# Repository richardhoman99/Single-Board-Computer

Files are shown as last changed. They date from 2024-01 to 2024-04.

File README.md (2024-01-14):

# Single Board Computer

CPGR4253 Microcomputer Design is not as much a technical course at LeTourneau University as it is a design project. The goal of the course is to design a functioning Single Board Computer with the following requirements:
- A microprocessor
- At least 64Kib RAM
- ROM memory to store monitor program
- Serial connection to external terminal

This repository is the container of all digital files supporting this project.

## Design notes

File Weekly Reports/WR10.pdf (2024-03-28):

Richard Homan

Microcomputer Design

Dr. Joonwan Kim

March 27, 2024

Design Report #10

I. Time: 15 Hours

II. Accomplishments

A. Programmed working CPLD program
B. Successfully programed ROM

III. Planned Work

A. Figure out halting issue
B. Run ROM/RAM test program
C. Run DUART base code and pass characters from board to laptop

IV. Project Completion

A. Hardware: 98%; Assembly complete, actively looking out for mistakes during software testing
B. Software: 85%; Monitor program 95% done, serial recognized and able to accept characters
V. Help from Lab Tech
A. n/a

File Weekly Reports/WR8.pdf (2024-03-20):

Richard Homan

Microcomputer Design

Dr. Joonwan Kim

March 6, 2024

Design Report #8

I. Time: 5 Hours

II. Accomplishments

A. Began soldering board

III. Planned Work

A. Complete board assembly
B. Program CPLD logic
C. Test burn EEPROM

IV. Project Completion

A. Hardware: 95%; Assembly almost complete
B. Software: 75%; Monitor program 95% done
V. Help from Lab Tech
A. n/a

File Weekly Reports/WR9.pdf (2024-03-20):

Richard Homan

Microcomputer Design

Dr. Joonwan Kim

March 20, 2024

Design Report #9

I. Time: 16 Hours

II. Accomplishments

A. Completed soldering board
B. Found power and serial issues with board, rectified by cutting traces
C. Board serial successfully recognized by Mac and Windows machines
D. Successfully programmed CPLD with test program

III. Planned Work

A. Write CPLD logic
B. Write serial test program
C. Burn serial test program onto ROM and test functionality
D. Combine serial and written monitor program, burn to ROM, and test

IV. Project Completion

A. Hardware: 98%; Assembly complete, actively looking out for mistakes during software testing
B. Software: 80%; Monitor program 95% done, serial recognized and able to accept characters
V. Help from Lab Tech
A. n/a

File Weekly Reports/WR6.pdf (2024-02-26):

Richard Homan

Microcomputer Design

Dr. Joonwan Kim

February 21, 2024

Design Report #6

I. Time: 22 Hours

II. Accomplishments

A. Finished monitor program on simulator

III. Planned Work

A. Receive and assemble board
B. Program CPLD logic
C. Test burn EEPROM

IV. Project Completion

A. Hardware: 90%; PCB ordered, parts recieved
B. Software: 75%; Monitor program 95% done
V. Help from Lab Tech
A. 2/15/23 - Basic checkup

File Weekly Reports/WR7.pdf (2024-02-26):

Richard Homan

Microcomputer Design

Dr. Joonwan Kim

February 28, 2024

Design Report #7

I. Time: 0 Hours

II. Accomplishments

A. n/a (Board ordered and shipped but still not received)

III. Planned Work

A. Receive and assemble board
B. Program CPLD logic
C. Test burn EEPROM

IV. Project Completion

A. Hardware: 90%; PCB ordered, parts received
B. Software: 75%; Monitor program 95% done
V. Help from Lab Tech
A. 2/22/23 - Basic checkup

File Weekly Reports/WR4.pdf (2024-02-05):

Richard Homan

Microcomputer Design

Dr. Joonwan Kim

February 7, 2024

Design Report #4

I. Time: 15 Hours

II. Accomplishments

A. PCB 99% complete

III. Planned Work

A. Finish PCB design and find a manufacturer
B. Set up C compiler environment
C. Begin software design

IV. Project Completion

A. Hardware: 75%; PCB almost ready to be manufactured
B. Software: 0%
V. Help from Lab Tech
A. 2/1/2024 - Discussed the future of MCD class

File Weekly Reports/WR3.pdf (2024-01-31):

Richard Homan

Microcomputer Design

Dr. Joonwan Kim

January 31, 2024

Design Report #3

I. Time: 26 Hours

II. Accomplishments

A. Parts are ordered
B. Final schematic complete
C. 85% done on PCB
D. Compared parts with peers
E. Had schematic reviewed

III. Planned Work

A. Finish PCB design and find a manufacturer

IV. Project Completion

A. Hardware: 60%; working on PCB
B. Software: 0%
V. Help from Lab Tech
A. 1/26/2024 - Reviewed final schematic and made recommended changes

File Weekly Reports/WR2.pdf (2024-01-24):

Microcomputer Design

Dr. Joonwan Kim

January 24, 2024

Design Report #2

I. Time: 13 Hours

II. Accomplishments

A. Researched more hardware options
B. Researched PCB manufacturing places to get specs on fabrication
C. Made schematic revision 0.2

III. Planned Work

A. Compare parts with peers
B. Create footprints for parts
C. Review schematic with Lab Assistant

IV. Project Completion

A. Hardware: 35%; Rev. 0.2 complete
B. Software: 0%
V. Help from Lab Tech
A. 1/18/2024 - Reviewed the CTS and RTS pin functions, looked over clock and reset circuit.

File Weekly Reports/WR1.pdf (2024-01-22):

Microcomputer Design

Dr. Joonwan Kim

January 18, 2024

Design Report #1

I. Time: 37 Hours

II. Accomplishments

A. Researched different hardware options; 95% confident in selection
B. Tested a few power switching circuit designs
C. Tested RAM circuit
D. Finished Rev. 0 of schematic

III. Planned Work

A. Review schematic and my custom symbols for correctness
B. Compare pinouts with peers
C. Compare parts lists with peers
D. Have schematic reviewed by lab tech

IV. Project Completion

A. Hardware: 30%; Rev. 0 complete
B. Software: 0%
V. Help from Lab Tech
A. 1/18/2024 - Reviewed the CTS and RTS pin functions, looked over clock and reset circuit.

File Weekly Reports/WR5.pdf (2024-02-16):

Richard Homan

Microcomputer Design

Dr. Joonwan Kim

February 14, 2024

Design Report #5

I. Time: 23 Hours

II. Accomplishments

A. Got C compiler and linker working for m68k
B. Finish memory and register modification and dumping for monitor program

III. Planned Work

A. Finish screcord loading and storing
B. Write executable to ROM

IV. Project Completion

A. Hardware: 90%; PCB ready to be manufactured
B. Software: 40%; Monitor program 45% done
V. Help from Lab Tech
A. 2/09/23 - Discuss which files get submitted to manufacturer

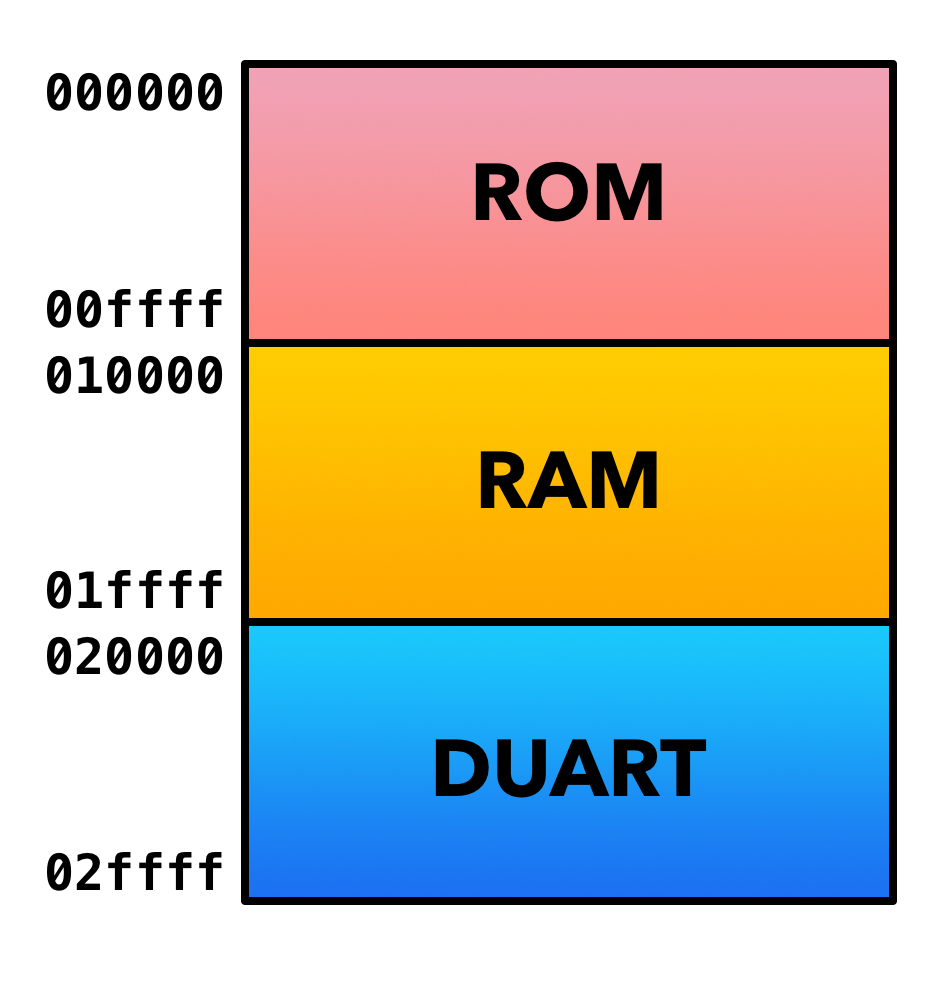
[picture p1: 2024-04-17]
Memory Map.png

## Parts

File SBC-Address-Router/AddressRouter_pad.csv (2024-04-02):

Release 8.1i - Fit P.20131013
Copyright(c) 1995-2003 Xilinx Inc. All rights reserved
4- 1-2024 2:27AM
NOTE: This file is designed to be imported into a spreadsheet program
such as Microsoft Excel for viewing | printing and sorting. The comma ' | '
character is used as the data field separator.
This file is also designed to support parsing.
Input file: AddressRouter.ngd
output file: AddressRouter_pad.csv
Part type: xc9572xl
Speed grade: -10
Package: pc44
Pinout by Pin Number:
----- | ----- | ----- | ----- | ----- | ----- | ----- | ----- | ----- | -----
Pin Number | Signal Name | Pin Usage | Pin Name | Direction | IO Standard | IO Bank Number | {blank} | Slew Rate | Termination | {blank} | Voltage | Constraint
P1 | o_cs_duart | O | I/O | OUTPUT
P2 | i_duart_dtack | I | I/O | INPUT
P3 | o_duart_rw | O | I/O | OUTPUT
P4 | TIE |  | I/O
P5 | i_clk | GCK | I/O/GCK1
P6 | o_oe | O | I/O/GCK2 | OUTPUT
P7 | o_we | O | I/O/GCK3 | OUTPUT
P8 | o_cs_ramh | O | I/O | OUTPUT
P9 | o_cs_raml | O | I/O | OUTPUT
P10 | GND |  | GND
P11 | TIE |  | I/O
P12 | o_ipl<0> | O | I/O | OUTPUT
P13 | TIE |  | I/O
P14 | o_ipl<1> | O | I/O | OUTPUT
P15 | TDI |  | TDI
P16 | TMS |  | TMS
P17 | TCK |  | TCK
P18 | o_berr | O | I/O | OUTPUT
P19 | TIE |  | I/O
P20 | o_ipl<2> | O | I/O | OUTPUT
P21 | VCC |  | VCCINT
P22 | o_hlt | O | I/O | OUTPUT
P23 | GND |  | GND
P24 | o_dtack | O | I/O | OUTPUT
P25 | i_rw | I | I/O | INPUT
P26 | i_lds | I | I/O | INPUT
P27 | i_uds | I | I/O | INPUT
P28 | i_as | I | I/O | INPUT
P29 | TIE |  | I/O
P30 | TDO |  | TDO
P31 | GND |  | GND
P32 | VCC |  | VCCIO
P33 | TIE |  | I/O
P34 | TIE |  | I/O
P35 | TIE |  | I/O
P36 | TIE |  | I/O
P37 | i_addr<1> | I | I/O | INPUT
P38 | TIE |  | I/O
P39 | i_addr<0> | I | I/O/GSR | INPUT
P40 | o_cs_roml | O | I/O/GTS2 | OUTPUT
P41 | VCC |  | VCCINT
P42 | o_duart_iack | O | I/O/GTS1 | OUTPUT
P43 | o_cs_romh | O | I/O | OUTPUT
P44 | i_rst | I | I/O | INPUT
To preserve the pinout above for future design iterations in
Project Navigator simply execute the (Lock Pins) process
located under the (Implement Design) process in a toolbox named
(Optional Implementation Tools) or invoke PIN2UCF from the
command line. The location constraints will be written into your
specified UCF file

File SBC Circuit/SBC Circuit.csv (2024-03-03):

Source: | /Users/richardhoman/Education/2024-Spring/CPGR4253/SBC Circuit/SBC Circuit.kicad_sch
Date: | Friday, March 01, 2024 at 03:02:21 PM
Tool: | Eeschema 7.0.10
Generator: | /Applications/KiCad/KiCad.app/Contents/SharedSupport/plugins/bom_csv_grouped_by_value.py
Component Count: | 89
Collated Components:
Item | Qty | Reference(s) | Value | LibPart | Footprint | Datasheet | DNP | ROLE | Role | Role2 | Sim.Device | Sim.Pins
1 | 3 | C1, C2, C3 | 4.7u | Device:C_Polarized_US | Capacitor_THT:CP_Radial_D4.0mm_P2.00mm | ~
2 | 1 | C4 | 10n | Device:C | Capacitor_THT:CP_Disc_L5.50mm_W4.00mm_P2.50mm_NonPolarized | ~
3 | 9 | C5, C6, C8, C10, C12, C14, C16, C18, C30 | 0.1u | Device:C | Capacitor_THT:CP_Disc_L5.50mm_W4.00mm_P2.50mm_NonPolarized | ~
4 | 13 | C7, C9, C11, C13, C15, C17, C19, C21, C23, C25, C27, C29, C31 | 1u | Device:C | Capacitor_THT:CP_Disc_L5.50mm_W4.00mm_P2.50mm_NonPolarized | ~
5 | 6 | C20, C22, C24, C26, C28, C32 | .1u | Device:C | Capacitor_THT:CP_Disc_L5.50mm_W4.00mm_P2.50mm_NonPolarized | ~
6 | 2 | C33, C34 | 47p | Device:C | Capacitor_THT:CP_Disc_L5.50mm_W4.00mm_P2.50mm_NonPolarized | ~
7 | 2 | D1, D2 | 1N4001 | Diode:1N4933-T | Diode_THT:D_DO-41_SOD81_P5.08mm_Vertical_KathodeUp | http://www.vishay.com/docs/88503/1n4001.pdf |  |  | BACKFLOW RECTIFIER |  | D | 1=K 2=A
8 | 4 | D3, D4, D5, D6 | LED | Device:LED | LED_THT:LED_D5.0mm | ~
9 | 2 | F1, F2 | 250mA Fuse | Device:Fuse | Fuse:Fuseholder_Clip-5x20mm_Bel_FC-203-22_Lateral_P17.80x5.00mm_D1.17mm_Horizontal | ~
10 | 1 | FB1 | FerriteBead | Device:FerriteBead | Capacitor_THT:C_Axial_L3.8mm_D2.6mm_P10.00mm_Horizontal | ~
11 | 1 | J1 | USB_B | Connector:USB_B | Connector_USB:USB_B_OST_USB-B1HSxx_Horizontal | ~
12 | 2 | J2, J8 | Conn_01x02_Pin | Connector:Conn_01x02_Pin | Connector_PinHeader_2.54mm:PinHeader_1x02_P2.54mm_Vertical | ~ |  |  | POWER IN
13 | 3 | J3, J4, J7 | Conn_01x06_Pin | Connector:Conn_01x06_Pin | Connector_PinHeader_2.54mm:PinHeader_1x06_P2.54mm_Vertical | ~ |  | PERIPHERAL IN | USB SERIAL CONVERTER HEADER
14 | 1 | J5 | Conn_01x03_Pin | Connector:Conn_01x03_Pin | Connector_PinHeader_2.54mm:PinHeader_1x03_P2.54mm_Vertical | ~ |  |  | PERIPHERAL POWER
15 | 1 | J6 | Conn_01x08_Pin | Connector:Conn_01x08_Pin | Connector_PinHeader_2.54mm:PinHeader_1x08_P2.54mm_Vertical | ~ |  |  | PERIPHERAL OUT
16 | 1 | J9 | Conn_02x04_Odd_Even | Connector_Generic:Conn_02x04_Odd_Even | Connector_PinHeader_2.54mm:PinHeader_2x04_P2.54mm_Vertical | ~ |  |  | CHANNEL SELECT
17 | 2 | Q1, Q2 | AOI21357 | Transistor_FET:AOI21357 | Package_TO_SOT_THT:TO-220-3_Vertical | http://www.irf.com/product-info/datasheets/data/irf9540n.pdf |  |  | 5V SOURCE SWITCHER
18 | 1 | R1 | 1M | Device:R | Resistor_THT:R_Axial_DIN0204_L3.6mm_D1.6mm_P2.54mm_Vertical | ~ |  |  | LOW WASTE PULLDOWN
19 | 2 | R2, R3 | 27 | Device:R | Resistor_THT:R_Axial_DIN0204_L3.6mm_D1.6mm_P2.54mm_Vertical | ~
20 | 5 | R4, R5, R6, R8, R13 | 10k | Device:R | Resistor_THT:R_Axial_DIN0204_L3.6mm_D1.6mm_P2.54mm_Vertical | ~
21 | 1 | R7 | 5.6k | Device:R | Resistor_THT:R_Axial_DIN0204_L3.6mm_D1.6mm_P2.54mm_Vertical | ~
22 | 1 | R9 | 470 | Device:R | Resistor_THT:R_Axial_DIN0204_L3.6mm_D1.6mm_P2.54mm_Vertical | ~
23 | 3 | R10, R11, R12 | 220 | Device:R | Resistor_THT:R_Axial_DIN0204_L3.6mm_D1.6mm_P2.54mm_Vertical | ~
24 | 1 | SW1 | RESET | Switch:SW_Push | Button_Switch_THT:SW_PUSH_6mm | ~
25 | 1 | TP1 | GND POINT | Connector:TestPoint | TestPoint:TestPoint_Keystone_5000-5004_Miniature | ~
26 | 1 | TP2 | 5V TEST | Connector:TestPoint | TestPoint:TestPoint_Keystone_5000-5004_Miniature | ~
27 | 1 | TP3 | 3.3V TEST | Connector:TestPoint | TestPoint:TestPoint_Keystone_5000-5004_Miniature | ~
28 | 1 | TP4 | ~{RST} | Connector:TestPoint | TestPoint:TestPoint_Keystone_5000-5004_Miniature | ~
29 | 1 | TP5 | VBUS SENSE | Connector:TestPoint | TestPoint:TestPoint_Keystone_5000-5004_Miniature | ~
30 | 1 | TP6 | ~{AS} | Connector:TestPoint | TestPoint:TestPoint_Keystone_5000-5004_Miniature | ~
31 | 1 | TP7 | ~{DTACK} | Connector:TestPoint | TestPoint:TestPoint_Keystone_5000-5004_Miniature | ~
32 | 1 | TP8 | ~{BERR} | Connector:TestPoint | TestPoint:TestPoint_Keystone_5000-5004_Miniature | ~
33 | 1 | U1 | MC68000FN | CPU_NXP_68000:MC68000FN | Package_LCC:PLCC-68_THT-Socket | https://www.nxp.com/docs/en/reference-manual/MC68000UM.pdf |  |  | MICROPROCESSOR
34 | 1 | U2 | XC9572XL | CPLD_Xilinx:XC9572XL-PC44 | Package_LCC:PLCC-44_THT-Socket |  |  |  |  | ADDRESS ROUTER
35 | 1 | U3 | 68681 | Interface:68681 | Package_DIP:DIP-40_W15.24mm_Socket |  |  |  | DUART
36 | 2 | U4, U5 | MCM6206CP | Memory_RAM:MCM6206CP | Package_DIP:DIP-28_W7.62mm_Socket | https://www.futurlec.com/Datasheet/Memory/62256.pdf |  |  | LOW
37 | 2 | U6, U7 | 28C256 | Memory_EEPROM:28C256 | Package_DIP:DIP-28_W15.24mm_Socket | http://ww1.microchip.com/downloads/en/DeviceDoc/doc0006.pdf |  |  | LOW
38 | 1 | U8 | LM7805_TO220 | Regulator_Linear:LM7805_TO220 | Package_TO_SOT_THT:TO-220-3_Vertical | https://www.onsemi.cn/PowerSolutions/document/MC7800-D.PDF |  |  | 5V REGULATOR
39 | 1 | U9 | LD1117AV33 | Regulator_Linear:LD1117-3.3 | Package_TO_SOT_THT:TO-220-3_Vertical | http://www.diodes.com/datasheets/AP1117.pdf |  |  | 3V REGULATOR
40 | 1 | U10 | FT230XS | Interface_USB:FT230XS | Package_SO:SSOP-16_3.9x4.9mm_P0.635mm | https://www.ftdichip.com/Support/Documents/DataSheets/ICs/DS_FT230X.pdf |  |  | SERIAL CONVERTER
41 | 1 | U11 | MC34064P | Power_Supervisor:MC34064P | Package_TO_SOT_THT:TO-92_Inline | https://www.onsemi.com/pub/Collateral/MC34064-D.PDF
42 | 1 | X1 | SG-531 | Oscillator:SG-531 | Oscillator:Oscillator_SeikoEpson_SG-8002DC | https://support.epson.biz/td/api/doc_check.php?mode=dl&lang=en&Parts=SG-51P |  |  | OSCILLATOR
43 | 1 | X2 | EC11 | Oscillator:EC11 | Oscillator:Oscillator_DIP-8 | https://support.epson.biz/td/api/doc_check.php?mode=dl&lang=en&Parts=SG-8002DC |  |  | DUART OSCILLATOR

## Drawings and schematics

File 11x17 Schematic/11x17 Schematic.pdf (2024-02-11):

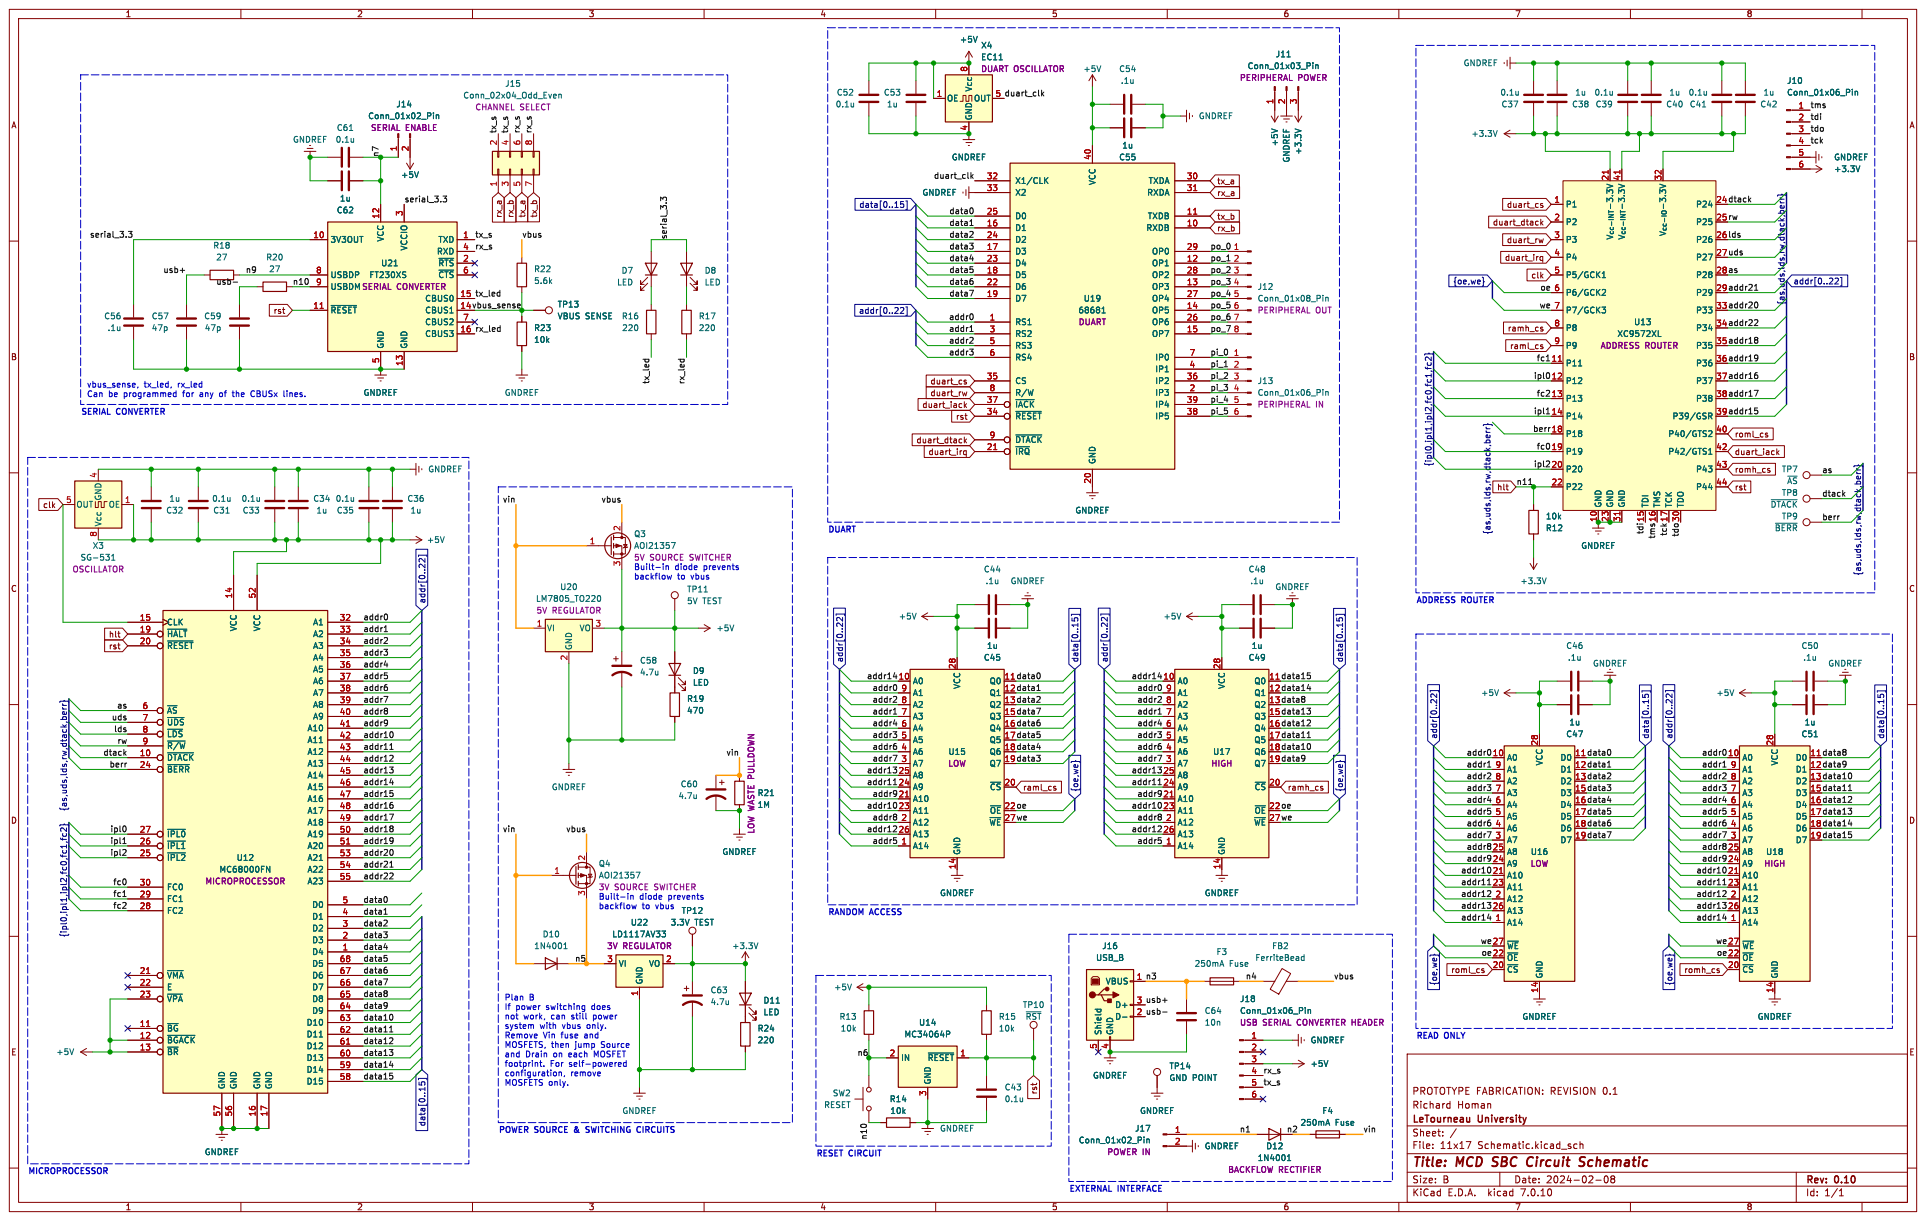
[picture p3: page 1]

4 OUT 5 Vcc 8 X4EC11 DUART OSCILLATOR

J11 Conn_01x03_Pin PERIPHERAL POWER GNDREF +5V GNDREF GNDREF

TP7~{AS} TP8 ~{DTACK} TP9 ~{BERR} GNDREF

4 OUT 5 Vcc 8 X3 SG-531 OSCILLATOR

READ ONLY RANDOM ACCESS

J18 Conn_01x06_Pin USB SERIAL CONVERTER HEADER

and Drain on each MOSFET

Id: 1/1 Title: MCD SBC Circuit Schematic

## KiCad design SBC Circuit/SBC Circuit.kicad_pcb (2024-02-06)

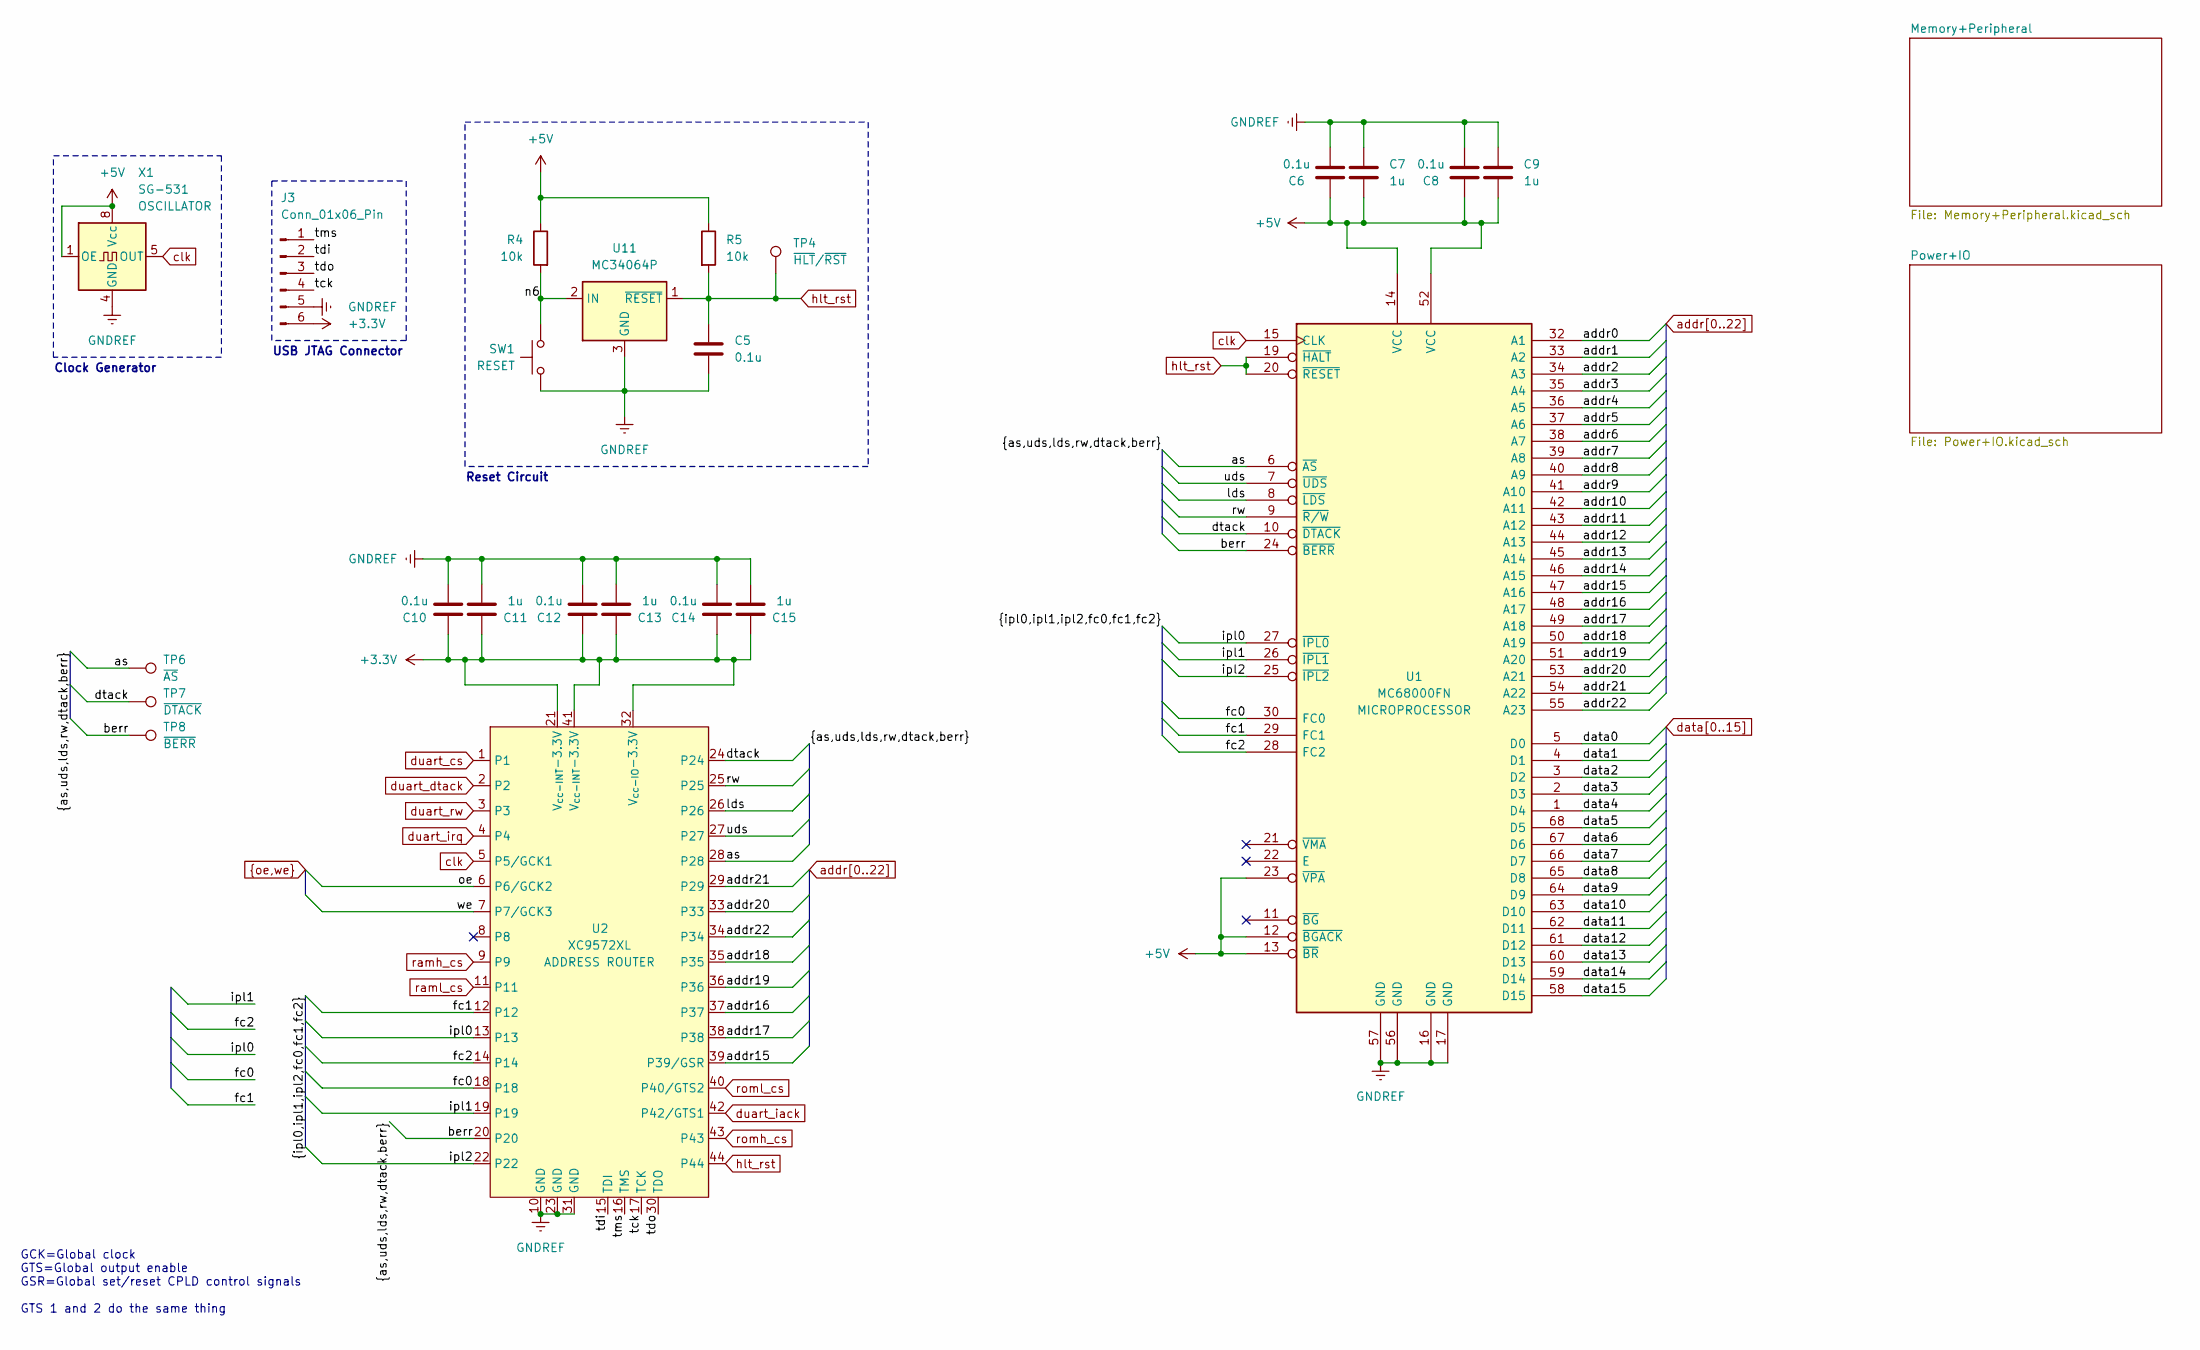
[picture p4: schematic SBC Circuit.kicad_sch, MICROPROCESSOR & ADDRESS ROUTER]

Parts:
C5, C6, C8, C10, C12, C14: 0.1u; CP_Disc_L5.50mm_W4.00mm_P2.50mm_NonPolarized
C7, C9, C11, C13, C15: 1u; CP_Disc_L5.50mm_W4.00mm_P2.50mm_NonPolarized
J3: Conn_01x06_Pin; PinHeader_1x06_P2.54mm_Vertical
R4, R5: 10k; R_Axial_DIN0204_L3.6mm_D1.6mm_P2.54mm_Vertical
SW1: RESET; SW_PUSH_6mm
TP4: ~{HLT}/~{RST}; TestPoint_Keystone_5000-5004_Miniature
TP6: ~{AS}; TestPoint_Keystone_5000-5004_Miniature
TP7: ~{DTACK}; TestPoint_Keystone_5000-5004_Miniature
TP8: ~{BERR}; TestPoint_Keystone_5000-5004_Miniature
U1: MC68000FN; PLCC-68_THT-Socket
U2: XC9572XL; PLCC-44_THT-Socket
U11: MC34064P; TO-92_Inline
X1: SG-531; Oscillator_SeikoEpson_SG-8002DC

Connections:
+3.3V: C10.1, C11.1, C12.1, C13.1, C14.1, C15.1, J3.6, U2.21 (V_{cc-INT}-3.3V), U2.32 (V_{cc-IO}-3.3V), U2.41 (V_{cc-INT}-3.3V); also elsewhere on the board
+5V: C6.1, C7.1, C8.1, C9.1, R4.1, R5.1, U1.12 (~BGACK), U1.13 (~BR), U1.14 (VCC), U1.23 (~VPA), U1.52 (VCC), X1.1 (OE), X1.8 (Vcc); also elsewhere on the board
/as: TP6.1, U1.6 (~AS), U2.28
/berr: TP8.1, U1.24 (~BERR), U2.20
/dtack: TP7.1, U1.10 (~DTACK), U2.24
/fc0: U1.30 (FC0), U2.18
/fc1: U1.29 (FC1), U2.12
/fc2: U1.28 (FC2), U2.14
/ipl0: U1.27 (~IPL0), U2.13
/ipl1: U1.26 (~IPL1), U2.19
/ipl2: U1.25 (~IPL2), U2.22
/lds: U1.8 (~LDS), U2.26
/n6: R4.2, SW1.1, U11.2 (IN)
/rw: U1.9 (~R/W), U2.25
/tck: J3.4, U2.17 (TCK)
/tdi: J3.2, U2.15 (TDI)
/tdo: J3.3, U2.30 (TDO)
/tms: J3.1, U2.16 (TMS)
/uds: U1.7 (~UDS), U2.27
GNDREF: C5.2, C6.2, C7.2, C8.2, C9.2, C10.2, C11.2, C12.2, C13.2, C14.2, C15.2, J3.5, SW1.2, U1.16 (GND), U1.17 (GND), U1.56 (GND), U1.57 (GND), U2.10 (GND), U2.23 (GND), U2.31 (GND), U11.3 (GND), X1.4 (GND); also elsewhere on the board
addr0: U1.32 (A1); also elsewhere on the board
addr1: U1.33 (A2); also elsewhere on the board
addr2: U1.34 (A3); also elsewhere on the board
addr3: U1.35 (A4); also elsewhere on the board
addr4: U1.36 (A5); also elsewhere on the board
addr5: U1.37 (A6); also elsewhere on the board
addr6: U1.38 (A7); also elsewhere on the board
addr7: U1.39 (A8); also elsewhere on the board
addr8: U1.40 (A9); also elsewhere on the board
addr9: U1.41 (A10); also elsewhere on the board
addr10: U1.42 (A11); also elsewhere on the board
addr11: U1.43 (A12); also elsewhere on the board
addr12: U1.44 (A13); also elsewhere on the board
addr13: U1.45 (A14); also elsewhere on the board
addr14: U1.46 (A15); also elsewhere on the board
addr15: U1.47 (A16), U2.39 (P39/GSR)
addr16: U1.48 (A17), U2.37
addr17: U1.49 (A18), U2.38
addr18: U1.50 (A19), U2.35
addr19: U1.51 (A20), U2.36
addr20: U1.53 (A21), U2.33
addr21: U1.54 (A22), U2.29
addr22: U1.55 (A23), U2.34
clk: U1.15 (CLK), U2.5 (P5/GCK1), X1.5 (OUT)
data0: U1.5 (D0); also elsewhere on the board
data1: U1.4 (D1); also elsewhere on the board
data2: U1.3 (D2); also elsewhere on the board
data3: U1.2 (D3); also elsewhere on the board
data4: U1.1 (D4); also elsewhere on the board
data5: U1.68 (D5); also elsewhere on the board
data6: U1.67 (D6); also elsewhere on the board
data7: U1.66 (D7); also elsewhere on the board
data8: U1.65 (D8); also elsewhere on the board
data9: U1.64 (D9); also elsewhere on the board
data10: U1.63 (D10); also elsewhere on the board
data11: U1.62 (D11); also elsewhere on the board
data12: U1.61 (D12); also elsewhere on the board
data13: U1.60 (D13); also elsewhere on the board
data14: U1.59 (D14); also elsewhere on the board
data15: U1.58 (D15); also elsewhere on the board
duart_cs: U2.1; also elsewhere on the board
duart_dtack: U2.2; also elsewhere on the board
duart_iack: U2.42 (P42/GTS1); also elsewhere on the board
duart_irq: U2.4; also elsewhere on the board
duart_rw: U2.3; also elsewhere on the board
hlt_rst: C5.1, R5.2, TP4.1, U1.19 (~HALT), U1.20 (~RESET), U2.44, U11.1 (~RESET); also elsewhere on the board
oe: U2.6 (P6/GCK2); also elsewhere on the board
ramh_cs: U2.9; also elsewhere on the board
raml_cs: U2.11; also elsewhere on the board
romh_cs: U2.43; also elsewhere on the board
roml_cs: U2.40 (P40/GTS2); also elsewhere on the board
we: U2.7 (P7/GCK3); also elsewhere on the board

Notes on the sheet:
Reset Circuit
USB JTAG Connector
GCK=Global clock GTS=Global output enable GSR=Global set/reset CPLD control signals GTS 1 and 2 do the same thing
Clock Generator

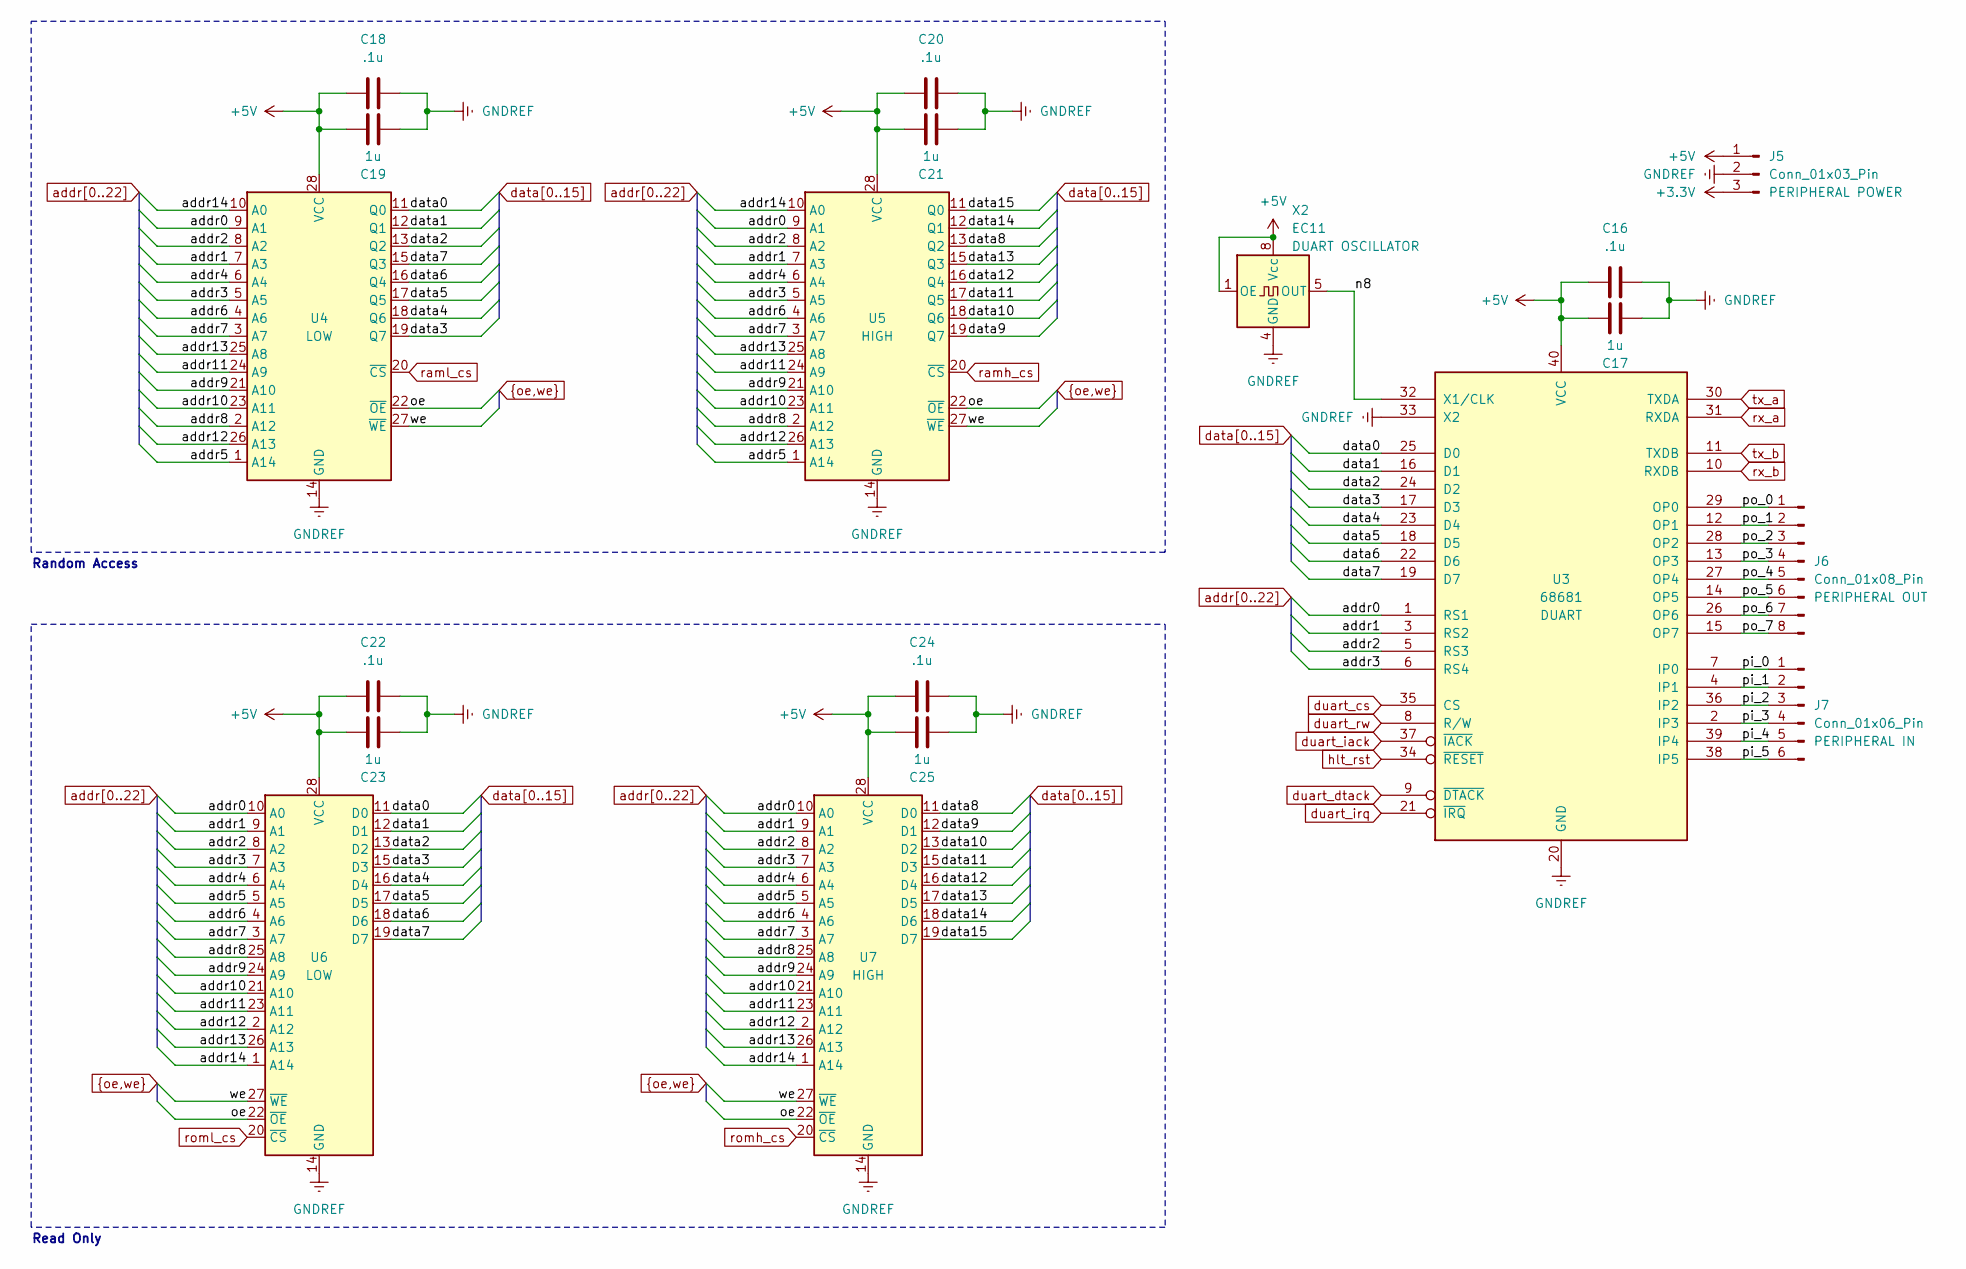
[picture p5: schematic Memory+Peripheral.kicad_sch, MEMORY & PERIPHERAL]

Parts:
C16, C18, C20, C22, C24: .1u; CP_Disc_L5.50mm_W4.00mm_P2.50mm_NonPolarized
C17, C19, C21, C23, C25: 1u; CP_Disc_L5.50mm_W4.00mm_P2.50mm_NonPolarized
J5: Conn_01x03_Pin; PinHeader_1x03_P2.54mm_Vertical
J6: Conn_01x08_Pin; PinHeader_1x08_P2.54mm_Vertical
J7: Conn_01x06_Pin; PinHeader_1x06_P2.54mm_Vertical
U3: 68681; DIP-40_W15.24mm_Socket
U4, U5: MCM6206CP; DIP-28_W7.62mm_Socket
U6, U7: 28C256; DIP-28_W15.24mm_Socket
X2: EC11; Oscillator_DIP-8

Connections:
+3.3V: J5.3; also elsewhere on the board
+5V: C16.1, C17.1, C18.1, C19.1, C20.1, C21.1, C22.1, C23.1, C24.1, C25.1, J5.1, U3.40 (VCC), U4.28 (VCC), U5.28 (VCC), U6.28 (VCC), U7.28 (VCC), X2.1 (OE), X2.8 (Vcc); also elsewhere on the board
/Memory+Peripheral/n8: U3.32 (X1/CLK), X2.5 (OUT)
/Memory+Peripheral/pi_0: J7.1, U3.7 (IP0)
/Memory+Peripheral/pi_1: J7.2, U3.4 (IP1)
/Memory+Peripheral/pi_2: J7.3, U3.36 (IP2)
/Memory+Peripheral/pi_3: J7.4, U3.2 (IP3)
/Memory+Peripheral/pi_4: J7.5, U3.39 (IP4)
/Memory+Peripheral/pi_5: J7.6, U3.38 (IP5)
/Memory+Peripheral/po_0: J6.1, U3.29 (OP0)
/Memory+Peripheral/po_1: J6.2, U3.12 (OP1)
/Memory+Peripheral/po_2: J6.3, U3.28 (OP2)
/Memory+Peripheral/po_3: J6.4, U3.13 (OP3)
/Memory+Peripheral/po_4: J6.5, U3.27 (OP4)
/Memory+Peripheral/po_5: J6.6, U3.14 (OP5)
/Memory+Peripheral/po_6: J6.7, U3.26 (OP6)
/Memory+Peripheral/po_7: J6.8, U3.15 (OP7)
GNDREF: C16.2, C17.2, C18.2, C19.2, C20.2, C21.2, C22.2, C23.2, C24.2, C25.2, J5.2, U3.20 (GND), U3.33 (X2), U4.14 (GND), U5.14 (GND), U6.14 (GND), U7.14 (GND), X2.4 (GND); also elsewhere on the board
addr0: U3.1 (RS1), U4.9 (A1), U5.9 (A1), U6.10 (A0), U7.10 (A0); also elsewhere on the board
addr1: U3.3 (RS2), U4.7 (A3), U5.7 (A3), U6.9 (A1), U7.9 (A1); also elsewhere on the board
addr2: U3.5 (RS3), U4.8 (A2), U5.8 (A2), U6.8 (A2), U7.8 (A2); also elsewhere on the board
addr3: U3.6 (RS4), U4.5 (A5), U5.5 (A5), U6.7 (A3), U7.7 (A3); also elsewhere on the board
addr4: U4.6 (A4), U5.6 (A4), U6.6 (A4), U7.6 (A4); also elsewhere on the board
addr5: U4.1 (A14), U5.1 (A14), U6.5 (A5), U7.5 (A5); also elsewhere on the board
addr6: U4.4 (A6), U5.4 (A6), U6.4 (A6), U7.4 (A6); also elsewhere on the board
addr7: U4.3 (A7), U5.3 (A7), U6.3 (A7), U7.3 (A7); also elsewhere on the board
addr8: U4.2 (A12), U5.2 (A12), U6.25 (A8), U7.25 (A8); also elsewhere on the board
addr9: U4.21 (A10), U5.21 (A10), U6.24 (A9), U7.24 (A9); also elsewhere on the board
addr10: U4.23 (A11), U5.23 (A11), U6.21 (A10), U7.21 (A10); also elsewhere on the board
addr11: U4.24 (A9), U5.24 (A9), U6.23 (A11), U7.23 (A11); also elsewhere on the board
addr12: U4.26 (A13), U5.26 (A13), U6.2 (A12), U7.2 (A12); also elsewhere on the board
addr13: U4.25 (A8), U5.25 (A8), U6.26 (A13), U7.26 (A13); also elsewhere on the board
addr14: U4.10 (A0), U5.10 (A0), U6.1 (A14), U7.1 (A14); also elsewhere on the board
data0: U3.25 (D0), U4.11 (Q0), U6.11 (D0); also elsewhere on the board
data1: U3.16 (D1), U4.12 (Q1), U6.12 (D1); also elsewhere on the board
data2: U3.24 (D2), U4.13 (Q2), U6.13 (D2); also elsewhere on the board
data3: U3.17 (D3), U4.19 (Q7), U6.15 (D3); also elsewhere on the board
data4: U3.23 (D4), U4.18 (Q6), U6.16 (D4); also elsewhere on the board
data5: U3.18 (D5), U4.17 (Q5), U6.17 (D5); also elsewhere on the board
data6: U3.22 (D6), U4.16 (Q4), U6.18 (D6); also elsewhere on the board
data7: U3.19 (D7), U4.15 (Q3), U6.19 (D7); also elsewhere on the board
data8: U5.13 (Q2), U7.11 (D0); also elsewhere on the board
data9: U5.19 (Q7), U7.12 (D1); also elsewhere on the board
data10: U5.18 (Q6), U7.13 (D2); also elsewhere on the board
data11: U5.17 (Q5), U7.15 (D3); also elsewhere on the board
data12: U5.16 (Q4), U7.16 (D4); also elsewhere on the board
data13: U5.15 (Q3), U7.17 (D5); also elsewhere on the board
data14: U5.12 (Q1), U7.18 (D6); also elsewhere on the board
data15: U5.11 (Q0), U7.19 (D7); also elsewhere on the board
duart_cs: U3.35 (CS); also elsewhere on the board
duart_dtack: U3.9 (~DTACK); also elsewhere on the board
duart_iack: U3.37 (~IACK); also elsewhere on the board
duart_irq: U3.21 (~IRQ); also elsewhere on the board
duart_rw: U3.8 (R/W); also elsewhere on the board
hlt_rst: U3.34 (~RESET); also elsewhere on the board
oe: U4.22 (~OE), U5.22 (~OE), U6.22 (~OE), U7.22 (~OE); also elsewhere on the board
ramh_cs: U5.20 (~CS); also elsewhere on the board
raml_cs: U4.20 (~CS); also elsewhere on the board
romh_cs: U7.20 (~CS); also elsewhere on the board
roml_cs: U6.20 (~CS); also elsewhere on the board
rx_a: U3.31 (RXDA); also elsewhere on the board
rx_b: U3.10 (RXDB); also elsewhere on the board
tx_a: U3.30 (TXDA); also elsewhere on the board
tx_b: U3.11 (TXDB); also elsewhere on the board
we: U4.27 (~WE), U5.27 (~WE), U6.27 (~WE), U7.27 (~WE); also elsewhere on the board

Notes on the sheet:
Read Only
Random Access

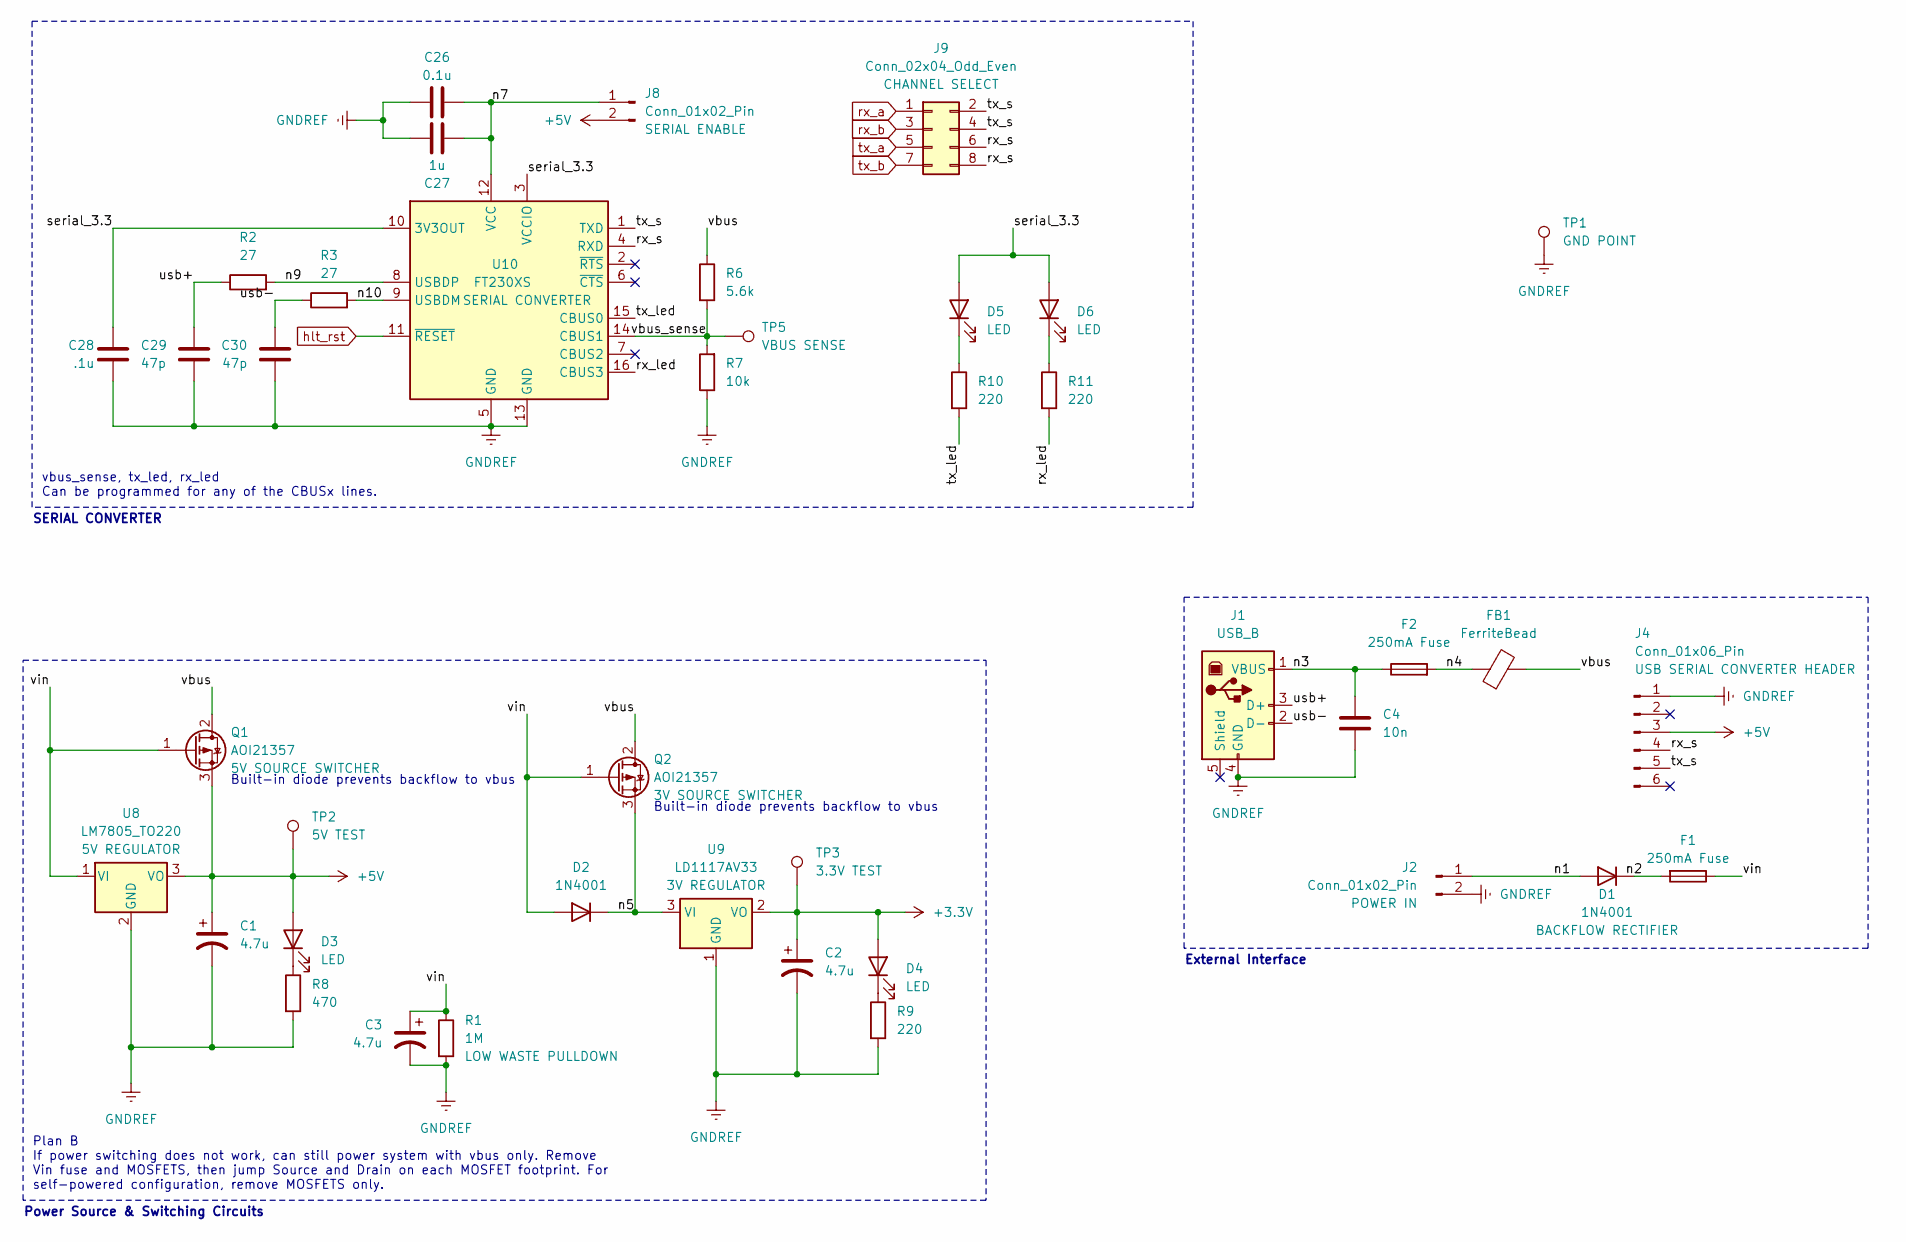
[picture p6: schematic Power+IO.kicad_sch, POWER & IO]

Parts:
C1, C2, C3: 4.7u; CP_Radial_D4.0mm_P2.00mm
C4: 10n; CP_Disc_L5.50mm_W4.00mm_P2.50mm_NonPolarized
C26: 0.1u; CP_Disc_L5.50mm_W4.00mm_P2.50mm_NonPolarized
C27: 1u; CP_Disc_L5.50mm_W4.00mm_P2.50mm_NonPolarized
C28: .1u; CP_Disc_L5.50mm_W4.00mm_P2.50mm_NonPolarized
C29, C30: 47p; CP_Disc_L5.50mm_W4.00mm_P2.50mm_NonPolarized
D1, D2: 1N4001; D_DO-41_SOD81_P5.08mm_Vertical_KathodeUp
D3, D4, D5, D6: LED; LED_D5.0mm
F1, F2: 250mA Fuse; Fuseholder_Clip-5x20mm_Bel_FC-203-22_Lateral_P17.80x5.00mm_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
FB1: FerriteBead; C_Axial_L3.8mm_D2.6mm_P10.00mm_Horizontal
J1: USB_B; USB_B_OST_USB-B1HSxx_Horizontal
J2, J8: Conn_01x02_Pin; PinHeader_1x02_P2.54mm_Vertical
J4: Conn_01x06_Pin; PinHeader_1x06_P2.54mm_Vertical
J9: Conn_02x04_Odd_Even; PinHeader_2x04_P2.54mm_Vertical
Q1, Q2: AOI21357; TO-220-3_Vertical
R1: 1M; R_Axial_DIN0204_L3.6mm_D1.6mm_P2.54mm_Vertical
R2, R3: 27; R_Axial_DIN0204_L3.6mm_D1.6mm_P2.54mm_Vertical
R6: 5.6k; R_Axial_DIN0204_L3.6mm_D1.6mm_P2.54mm_Vertical
R7: 10k; R_Axial_DIN0204_L3.6mm_D1.6mm_P2.54mm_Vertical
R8: 470; R_Axial_DIN0204_L3.6mm_D1.6mm_P2.54mm_Vertical
R9, R10, R11: 220; R_Axial_DIN0204_L3.6mm_D1.6mm_P2.54mm_Vertical
TP1: GND POINT; TestPoint_Keystone_5000-5004_Miniature
TP2: 5V TEST; TestPoint_Keystone_5000-5004_Miniature
TP3: 3.3V TEST; TestPoint_Keystone_5000-5004_Miniature
TP5: VBUS SENSE; TestPoint_Keystone_5000-5004_Miniature
U8: LM7805_TO220; TO-220-3_Vertical
U9: LD1117AV33; TO-220-3_Vertical
U10: FT230XS; SSOP-16_3.9x4.9mm_P0.635mm

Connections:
+3.3V: C2.1, D4.2 (A), TP3.1, U9.2 (VO); also elsewhere on the board
+5V: C1.1, D3.2 (A), J4.3, J8.2, Q1.3 (S), TP2.1, U8.3 (VO); also elsewhere on the board
/Power+IO/n1: D1.2 (A), J2.1
/Power+IO/n2: D1.1 (K), F1.2
/Power+IO/n3: C4.1, F2.1, J1.1 (VBUS)
/Power+IO/n4: F2.2, FB1.1
/Power+IO/n5: D2.1 (K), Q2.3 (S), U9.3 (VI)
/Power+IO/n7: C26.1, C27.1, J8.1, U10.12 (VCC)
/Power+IO/n9: R2.2, U10.8 (USBDP)
/Power+IO/n10: R3.2, U10.9 (USBDM)
/Power+IO/rx_led: R11.2, U10.16 (CBUS3)
/Power+IO/rx_s: J4.4, J9.6, J9.8, U10.4 (RXD)
/Power+IO/serial_3.3: C28.1, D5.2 (A), D6.2 (A), U10.3 (VCCIO), U10.10 (3V3OUT)
/Power+IO/tx_led: R10.2, U10.15 (CBUS0)
/Power+IO/tx_s: J4.5, J9.2, J9.4, U10.1 (TXD)
/Power+IO/usb+: C29.1, J1.3 (D+), R2.1
/Power+IO/usb-: C30.1, J1.2 (D-), R3.1
/Power+IO/vbus: FB1.2, Q1.2 (D), Q2.2 (D), R6.1
/Power+IO/vbus_sense: R6.2, R7.2, TP5.1, U10.14 (CBUS1)
/Power+IO/vin: C3.1, D2.2 (A), F1.1, Q1.1 (G), Q2.1 (G), R1.1, U8.1 (VI)
GNDREF: C1.2, C2.2, C3.2, C4.2, C26.2, C27.2, C28.2, C29.2, C30.2, J1.4 (GND), J2.2, J4.1, R1.2, R7.1, R8.2, R9.2, TP1.1, U8.2 (GND), U9.1 (GND), U10.5 (GND), U10.13 (GND); also elsewhere on the board
unnamed: D3.1 (K), R8.1
unnamed: D4.1 (K), R9.1
unnamed: D5.1 (K), R10.1
unnamed: D6.1 (K), R11.1
hlt_rst: U10.11 (~RESET); also elsewhere on the board
rx_a: J9.1; also elsewhere on the board
rx_b: J9.3; also elsewhere on the board
tx_a: J9.5; also elsewhere on the board
tx_b: J9.7; also elsewhere on the board

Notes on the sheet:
vbus_sense, tx_led, rx_led Can be programmed for any of the CBUSx lines.
Built-in diode prevents backflow to vbus
External Interface
SERIAL CONVERTER
Plan B If power switching does not work, can still power system with vbus only. Remove Vin fuse and MOSFETS, then jump Source and Drain on each MOSFET footprint. For self-powered configuration, remove MOSFETS only.
Power Source & Switching Circuits

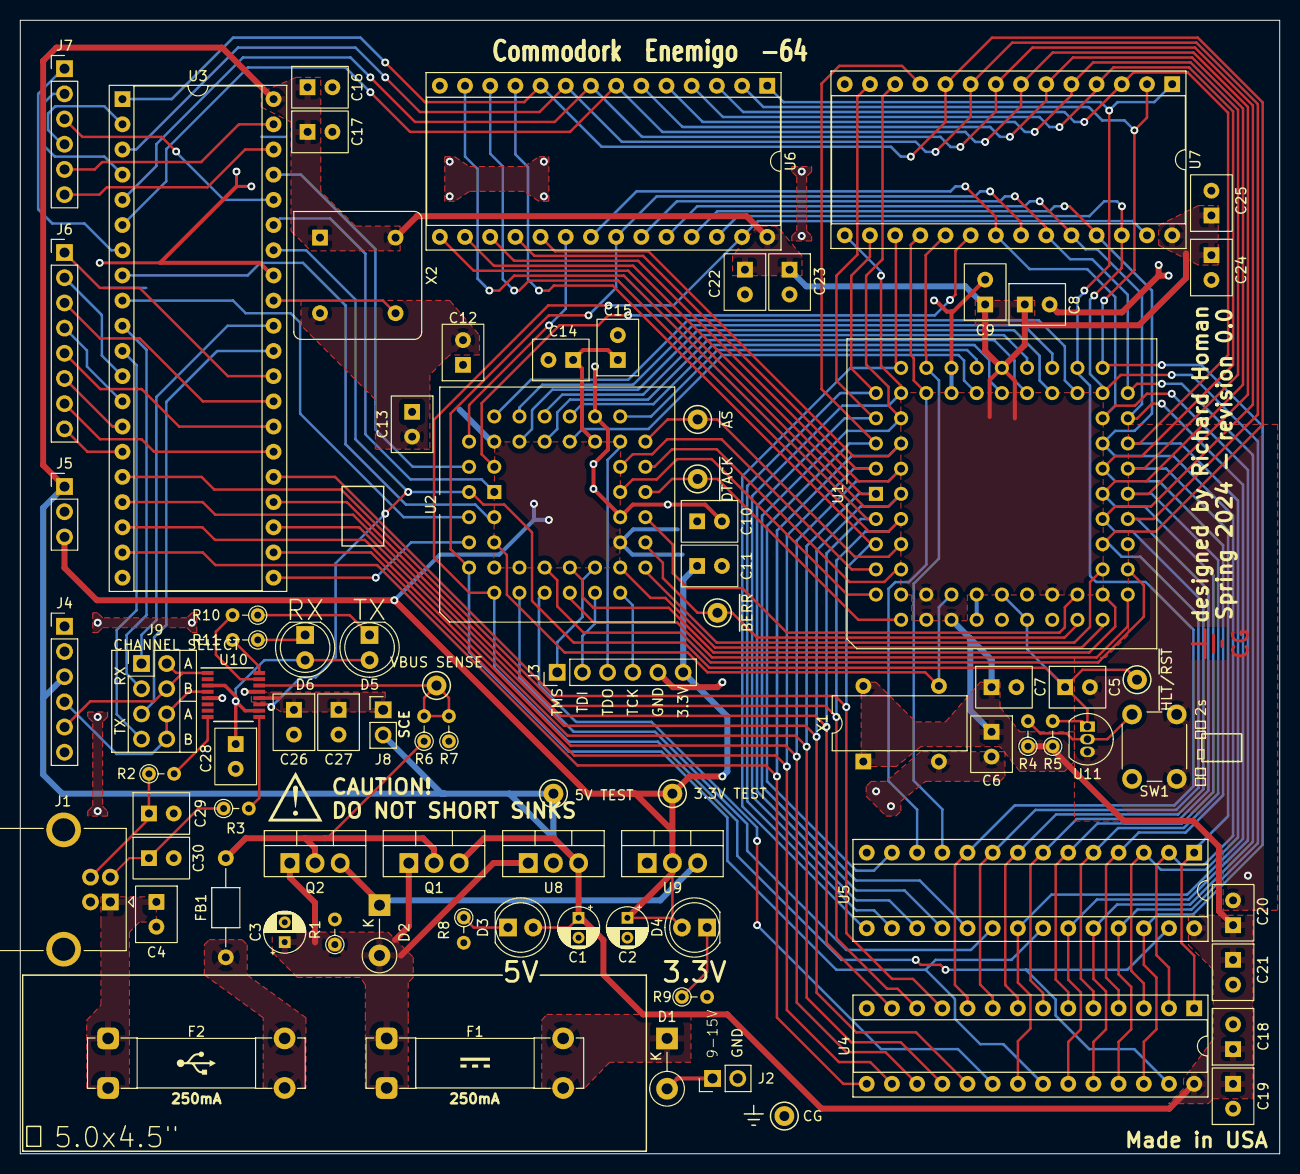
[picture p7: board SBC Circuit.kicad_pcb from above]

Board: 2 copper layers, 127.0 x 114.3 mm, 83 parts (0 on the bottom side), 113 nets.

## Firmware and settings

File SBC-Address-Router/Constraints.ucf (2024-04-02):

// MCD SBC Project
// Richard Homan
// 03/07/2024
// Constraints.ucf
// Target: XC9572XL-10PC44
// r0.1
// description:
//		User constraints file for SBC Address Router
// dependancies:
//		none

net "i_clk"         loc = "P05";
net "o_hlt"         loc = "P22";
net "i_rst"         loc = "P44";

net "o_oe"          loc = "P06";
net "o_we"          loc = "P07";
net "o_duart_rw"    loc = "P03";

net "o_cs_roml"     loc = "P40";
net "o_cs_romh"     loc = "P43";
net "o_cs_raml"     loc = "P09";
net "o_cs_ramh"     loc = "P08";
net "o_cs_duart"    loc = "P01";
	
net "o_duart_iack"  loc = "P42";
net "i_duart_dtack" loc = "P02";
net "i_duart_irq"   loc = "P04";
	
net "o_berr"        loc = "P18";
net "o_dtack"       loc = "P24";
net "i_rw"          loc = "P25";
net "i_lds"         loc = "P26";
net "i_uds"         loc = "P27";
net "i_as"          loc = "P28";
	
net "i_fc<0>"       loc = "P19";
net "i_fc<1>"       loc = "P11";
net "i_fc<2>"       loc = "P13";
net "o_ipl<0>"      loc = "P12";
net "o_ipl<1>"      loc = "P14";
net "o_ipl<2>"      loc = "P20";

net "i_addr<0>"     loc = "P39"; // 15
net "i_addr<1>"     loc = "P37"; // 16
net "i_addr<2>"     loc = "P38"; // 17
net "i_addr<3>"     loc = "P35"; // 18
net "i_addr<4>"     loc = "P36"; // 19
net "i_addr<5>"     loc = "P33"; // 20
net "i_addr<6>"     loc = "P29"; // 21
net "i_addr<7>"     loc = "P34"; // 22

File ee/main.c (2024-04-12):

/*
 * main.c
 * Richard Homan
 * 02/17/2024
 * Entry point for 80h game
 */

#include "types.h"
#include "convert.h"
#include "serial.h"

#define ARR_LEN(v) sizeof(v)/sizeof(v[0])

#define MOVE_LEFT(mutate)	move(mutate, 0, 0)
#define MOVE_RIGHT(mutate)	move(mutate, 1, 0)
#define MOVE_UP(mutate)		move(mutate, 0, 1)
#define MOVE_DOWN(mutate)	move(mutate, 1, 1)

#define WIN_NUM	0x80
#define WIN_NUM_STR "80"

const char welcome_str[] = "\
80h!\r\n\
Use I, J, K, and L to move the board.\r\n\
Get up to " WIN_NUM_STR " to win!\r\n\
Written by Richard Homan with inspiration from 2048 by Gabriele Cirulli\r\n\
\r\n\
PRESS ANY KEY\r\n";
const char clr_screen_str[] = "\033[2J";
const char row_divider_str[] = "+--+--+--+";
const char loss_str[] = "Game Over";
const char win_str[] = "You Win!";
const char nl_str[] = "\r\n";
const char blank_str[] = "  ";
const char ctrl_c_str[] = "^C";

ubyte board_values[3][3] __attribute__ ((aligned (4)));

void draw();
void init_values();
void clear_screen();

int order_init(int order);
int order_compare(int val, int low, int high, int order);
int order_next(int val, int order);
ubyte *value_ptr(int r, int c, int t); // 1 for transpose row and column
// >= 2 if 0x80 was reached, 1 if made changes, 0 otherwise
int move(int mutate, int order, int transpose);
// 1 if insertion could be made, 0 otherwise (game over)
// move_count use as "random generation seed"
int insert(int move_count);

int main(void)
{
	char c;
	int count, change;

	count = 0;
	init_values();

	// print welcome
	clear_screen();
	serial_puts(welcome_str, ARR_LEN(welcome_str));
	while (!serial_isc()) ;
	serial_getc(); // discard input

poll_user:
	draw();

	while (!serial_isc()) ;
	c = serial_getc();

	switch (c)
	{
	case 'i':
		change = MOVE_UP(1);
		break;
	case 'k':
		change = MOVE_DOWN(1);
		break;
	case 'j':
		change = MOVE_LEFT(1);
		break;
	case 'l':
		change = MOVE_RIGHT(1);
		break;
	case '\x03': // ctrl c
		serial_puts(ctrl_c_str, ARR_LEN(ctrl_c_str));
		serial_puts(nl_str, ARR_LEN(nl_str));
		return 0;
	default:
		change = 0;
		break;
	}

	if (change == 1)
	{
		if (!insert(count))
		{
			// couldn't insert any values, game over
			draw(); // show user the final board
			serial_puts(loss_str, ARR_LEN(loss_str));
			serial_puts(nl_str, ARR_LEN(nl_str));
			return 0;
		}
		count++;
	}
	else if (change >= 2)
	{
		draw();
		serial_puts(win_str, ARR_LEN(win_str));
		serial_puts(nl_str, ARR_LEN(nl_str));
		return 0;
	}

	goto poll_user;

	while (1)
		asm __volatile__ ("nop");
	return 0;
}

inline
void draw()
{
	register int i, j;
	char obuf[3];
	ubyte b;

	obuf[2] = '\0';
	clear_screen();
	serial_puts(row_divider_str, ARR_LEN(row_divider_str));
	serial_puts(nl_str, ARR_LEN(nl_str));

	for (i = 0; i < 3; i++)
	{
		serial_putc('|');
		for (j = 0; j < 3; j++)
		{
			b = board_values[i][j];
			if (b == 0)
			{
				serial_puts(blank_str, ARR_LEN(blank_str));
			}
			else
			{
				btoah(board_values[i][j], &(obuf[0]));
				serial_puts(obuf, 2);
			}
			serial_putc('|');
		}

		serial_puts(nl_str, ARR_LEN(nl_str));
		serial_puts(row_divider_str, ARR_LEN(row_divider_str));
		serial_puts(nl_str, ARR_LEN(nl_str));
	}
}

ubyte *value_ptr(int r, int c, int transpose)
{
	if (transpose) // column first
		return &(board_values[c][r]);
	// row first
	return &(board_values[r][c]);
}

int insert(int move_count)
{
	register int i;
	int s;
	register ubyte *p;
	
	i = move_count % 8;
	if (move_count % 2 == 0)
		i = 9-i;
	s = i;
	do
	{
		p = (ubyte *)((ubyte *)board_values + (ulword)i);
		if (*p == 0)
		{
			*p = move_count % 8 == 0 ? 2 : 1;
			s = 0;
			// check that we have more moves
			for (i = 0; i < 4; i++)
				s = s || move(0, i & 0x1, i & 0x2);
			return s;
		}
		i++;
		if (i >= 9)
			i = 0;
	}
	while (i != s);

	// no more open spots, no more moves
	return 0;
}

// 0,0: left
// 1,0: right
// 0,1: up
// 1,1: down
int move(int mutate, int order, int transpose)
{
	register int row, col, idx, len, n, c;
	register ubyte b;
	ubyte move[3];

	c = 0;
	for (row = 0; row < 3; row++)
	{
		len = !order ? order_init(order) : order_init(order)+1;
		for (col = order_init(order);
			 order_compare(col, 0, 3, order);
			 col = order_next(col, order))
		{
			b = *value_ptr(row, col, transpose);
			if (b != 0)
			{
				if (order) // predecrement
					len = order_next(len, order);
				move[len] = b;
				if (!order) // postincrement
					len = order_next(len, order);
			}
		}

		for (col = 1;
			 order_compare(col, len, len, order);
			 col = order_next(col, order))
		{
			n = order_next(col, !order);
			if (move[n] == move[col])
			{
				move[n] = move[n] << 1;
				move[col] = 0;
				if (move[n] == WIN_NUM)
					c = 2;
				else
					c |= 1; // keep win state
			}
		}

		col = order_init(order);
		for (idx = order_init(order);
			 order_compare(idx, len, len, order);
			 idx = order_next(idx, order))
		{
			b = move[idx];
			if (b != 0)
			{
				c = c | (*value_ptr(row, col, transpose) != move[idx]);
				if (mutate) *value_ptr(row, col, transpose) = move[idx];
				col = order_next(col, order);
			}
		}

		if (mutate)
		{
			for (;
				 order_compare(col, 0, 3, order);
				 col = order_next(col, order))
			{
				*value_ptr(row, col, transpose) = 0;
			}
		}
	}

	return c;
}

int order_init(int order)
{
	if (!order) // begin at bottom
		return 0;
	return 2; // begin at top
}

int order_compare(int val, int low, int high, int order)
{
	if (!order)
		return val < high;
	return val >= low;
}

int order_next(int val, int order)
{
	if (!order)
		return val+1;
	return val-1;
}

inline
void init_values()
{
	int i, j;
	for (i = 0; i < 3; i++)
	{
		for (j = 0; j < 3; j++)
		{
			board_values[i][j] = 0;
		}
	}

	board_values[0][0] = 1;
	board_values[0][2] = 1;
}

inline
void clear_screen()
{
#ifndef SIM
	serial_puts(clr_screen_str, ARR_LEN(clr_screen_str));
#else
	__asm__ __volatile__ ("move.l	%/d1,-(%/sp)\n"		// save registers
						  "move.l	%/d0,-(%/sp)\n"
						  "move.l	#0xff00,%/d1\n"		// clear screen
						  "move.w	#11,%/d0\n"			// task 11
						  "trap		#15\n"				// trap 15: SIM tasks
						  "move.l	(%/sp)+,%/d0\n"		// restore registers
						  "move.l	(%/sp)+,%/d1\n"
						  ::: "cc", "memory");
	return;
#endif
}

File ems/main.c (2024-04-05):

/*
 * main.c
 * Richard Homan
 * 02/11/2024
 * Entry point for Enemigo Monitor System
 */

#include "types.h"
#include "convert.h"
#include "strings.h"
#include "command.h"
#include "exec.h"
#include "serial.h"
#include "prompt.h"

#define INBUF_SIZE 16
#define ARG_MAX 3

const char parse_err_str[]  = "error parsing arguments";
const char inv_comm_str[]   = "unknown command";
const char bad_arg_str[]    = "bad argument";
const char noexecload_str[] = "no executable loaded";

const char pmt_str[] = "ems% ";

static char inbuf[INBUF_SIZE];
static char *argv[ARG_MAX];

byte has_exec;
int (*exec_entry_ptr)(void);

int main(void)
{
	int r;
	int inbuf_len;
	int argc;
	command_func command;

	has_exec = 0;
	exec_entry_ptr = 0x0;
	serial_init();

	serial_puts(welcome_str, WELCOME_STR_LEN);

mpmt:
	inbuf_len = user_prompt(inbuf, INBUF_SIZE, pmt_str, ARR_LEN(pmt_str), 0);

	r = split_args(inbuf, inbuf_len, argv, &argc, ARG_MAX);
	if (r != 0) // inform about error and return to prompt
	{
		serial_puts(parse_err_str, ARR_LEN(parse_err_str));
		serial_puts(nl_str, NL_STR_LEN);
		goto mpmt;
	}

	if (inbuf_len > 0)
	{
		command = gcommand(argv[0]);
		// serial_puts(argv[0], INBUF_SIZE);
		// goto mpmt;

		r = command((const char **)argv, argc);
	}
	else
		r = EMS_INV_COMM;

	switch (r)
	{
	case 0:
		break;
	case EMS_INV_COMM:
		serial_puts(inv_comm_str, ARR_LEN(inv_comm_str));
		break;
	case EMS_BAD_ARG:
		serial_puts(bad_arg_str, ARR_LEN(bad_arg_str));
		break;
	case EMS_NO_EXEC:
		serial_puts(noexecload_str, ARR_LEN(noexecload_str));
		break;
	default:
		serial_puts(err_str, ERR_STR_LEN);
		btoah((byte)(r & 0xff), &(inbuf[0]));
		serial_puts(inbuf, 2);
		break;
	}
	if (r != 0)
		serial_puts(nl_str, NL_STR_LEN);

	goto mpmt; // never exit

	// we should never get to this point, but if we do, loop
	while (1)
		__asm__ __volatile__ ("nop");
	return 0;
}

__attribute__ ((interrupt_handler))
void __access_error(void)
{
	serial_putc('~');

	while (1) // infinite loop trap
		__asm__ __volatile__ ("nop");
}

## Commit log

2024-01-15 Initial KiCad commit
    Wired up RAM and ROM
    Modified Parts List
    [SBC Circuit.kicad_pcb, SBC Circuit.kicad_sch]
2024-01-15 Design Schematic
    Rev 0 progress: 70%
    [Memory+Peripheral.kicad_sch, Power+IO.kicad_sch, SBC Circuit.kicad_sch]
2024-01-18 Updates to Schematic
    [Power+IO.kicad_sch]
2024-01-18 Small changes to prepare for review
    [Memory+Peripheral.kicad_sch, Power+IO.kicad_sch, SBC Circuit.kicad_sch]
2024-01-22 New part selections, serial port selection
    [Memory+Peripheral.kicad_sch, Power+IO.kicad_sch, SBC Circuit.kicad_pcb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]
2024-01-22 Update schematic version
    [Memory+Peripheral.kicad_sch, Power+IO.kicad_sch]
2024-01-22 Create footprints
2024-01-22 Add peripheral headers to schematic
    [Memory+Peripheral.kicad_sch, Power+IO.kicad_sch, SBC Circuit.kicad_sch]
2024-01-22 Reannotate schematic
    [Memory+Peripheral.kicad_sch, Power+IO.kicad_sch, SBC Circuit.kicad_sch]
2024-01-22 Assign Footprints
    [Memory+Peripheral.kicad_sch, Power+IO.kicad_sch, SBC Circuit.kicad_sch]
2024-01-22 Grouped footprints on PCB
    [Power+IO.kicad_sch, SBC Circuit.kicad_pcb]
2024-01-23 Fix intersheet bus issues
    [Memory+Peripheral.kicad_sch, Power+IO.kicad_sch, SBC Circuit.kicad_pcb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]
2024-01-24 PCB CPLD to MPU lines wired
    [Memory+Peripheral.kicad_sch, Power+IO.kicad_sch, SBC Circuit.kicad_pcb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]
2024-01-24 Wire reset circuit
    [SBC Circuit.kicad_pcb]
2024-01-24 Wire fuses and USB jack
    [SBC Circuit.kicad_pcb]
2024-01-25 Wire Serial
    [Power+IO.kicad_sch, SBC Circuit.kicad_pcb, SBC Circuit.kicad_sch]
2024-01-25 Set Serial circuit into place
    [SBC Circuit.kicad_pcb]
2024-01-25 Finish power and IO circuit
    [SBC Circuit.kicad_pcb, SBC Circuit.kicad_sch]
2024-01-26 Begin final PCB placement
    [Power+IO.kicad_sch, SBC Circuit.kicad_pcb, SBC Circuit.kicad_sch]
2024-01-26 Begin wiring DUART
    [SBC Circuit.kicad_pcb]
2024-01-26 Complete DUART lines
    [SBC Circuit.kicad_pcb]
2024-01-27 Finish DUART lines
    [Memory+Peripheral.kicad_sch, Power+IO.kicad_sch, SBC Circuit.kicad_pcb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]
2024-01-27 Update revision notes and time sheet
    [SBC Circuit.kicad_pcb]
2024-01-27 ROM high connected
    [SBC Circuit.kicad_pcb]
2024-01-27 Commit before design change
    [SBC Circuit.kicad_pcb]
2024-01-28 Wire ROM low
    [SBC Circuit.kicad_pcb]
2024-01-28 Finished wiring ROM High
    [Memory+Peripheral.kicad_sch, SBC Circuit.kicad_pcb]
2024-01-29 Wire high ROM correctly
    [Memory+Peripheral.kicad_sch, SBC Circuit.kicad_pcb]
2024-01-29 Add graphic
    [SBC Circuit.kicad_pcb]
2024-01-31 Create 11x17
    [11x17 Schematic.kicad_pcb, 11x17 Schematic.kicad_sch, SBC Circuit.kicad_pcb]
2024-01-31 Commit before design change 2
    [SBC Circuit.kicad_pcb]
2024-02-02 Wire phase done
    [Memory+Peripheral.kicad_sch, Power+IO.kicad_sch, SBC Circuit.kicad_pcb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]
2024-02-02 Connect some power lines
    [SBC Circuit.kicad_pcb, SBC Circuit.kicad_sch]
2024-02-04 All lines connected
    [Memory+Peripheral.kicad_sch, Power+IO.kicad_sch, SBC Circuit.kicad_pcb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]
2024-02-04 Add ground test point
    [Power+IO.kicad_sch, SBC Circuit.kicad_pcb, SBC Circuit.kicad_sch]
2024-02-04 Update font, add zones to fuses
    [Memory+Peripheral.kicad_sch, Power+IO.kicad_sch, SBC Circuit.kicad_pcb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]
2024-02-04 Update date
    [SBC Circuit.kicad_pcb]
2024-02-06 Make final adjustments before export
    [SBC Circuit.kicad_pcb]
2024-02-06 Export fab outputs for different countries
    [SBC Circuit-B_Cu.gbr, SBC Circuit-B_Mask.gbr, SBC Circuit-B_Paste.gbr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]
2024-02-07 Update schematic and PCB for requested changes
    [Memory+Peripheral.kicad_sch, Power+IO.kicad_sch, SBC Circuit.kicad_sch]
2024-02-09 Finalize PCB, neaten up Schematic
    [Memory+Peripheral.kicad_sch, Power+IO.kicad_sch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]
2024-02-11 Begin monitor development
    [11x17 Schematic.kicad_sch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]
2024-02-16 Begin srec parser error reporting
    [main.c]
2024-03-03 Update time sheet
    [SBC Circuit.csv]
2024-03-20 ISE files
    [AddressRouter_pad.csv]
2024-03-22 Finish AddressRouter VHDL
    [AddressRouter_pad.csv]
2024-03-22 Add AddressRouter program verification feature
    [AddressRouter_pad.csv]
2024-03-25 Debug AddressRouter logic
    [AddressRouter_pad.csv]
2024-03-25 Debug AddressRouter
    [AddressRouter_pad.csv]
2024-04-02 Update AddressRouter
    [AddressRouter_pad.csv]
